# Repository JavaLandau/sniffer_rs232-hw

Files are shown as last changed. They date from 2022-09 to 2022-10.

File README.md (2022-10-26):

# Hardware project for Sniffer RS-232
The repository contains Altium Designer project for Sniffer RS-232.  

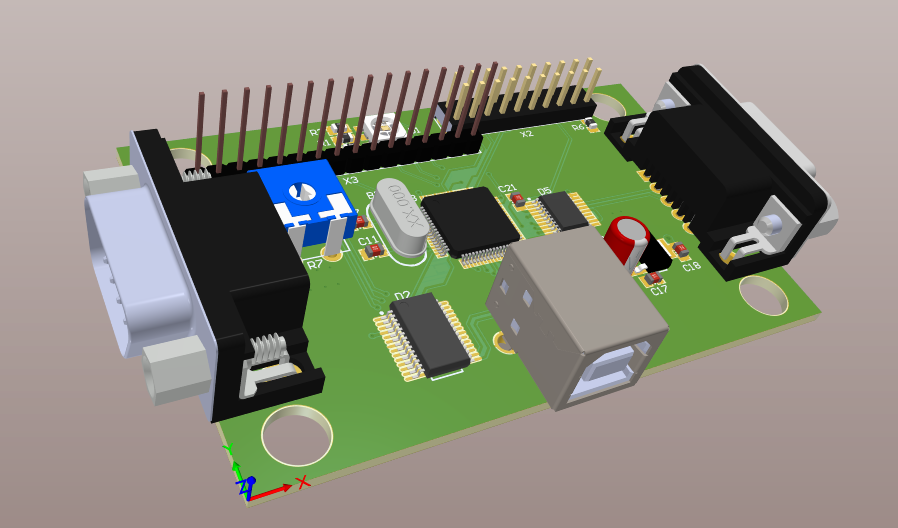
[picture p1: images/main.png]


Sniffer RS-232 is RS-232 autodetector & monitor which can recognize UART parameters on TX & RX RS-232 lines  
(baudrate, word length, parity bit) and output monitored data via USB using COM terminal (have been tested on [PuTTY](https://www.putty.org/) and [TeraTerm](https://ttssh2.osdn.jp/index.html.en)).  

The device is designed so to be connected to RS-232 line, passing traffic through itself working as repeater for TX & RX channels.  
It allows Sniffer RS-232 to be transparent for working of target devices which use RS-232. Scheme of normal work of Sniffer RS-232 is on picture below.

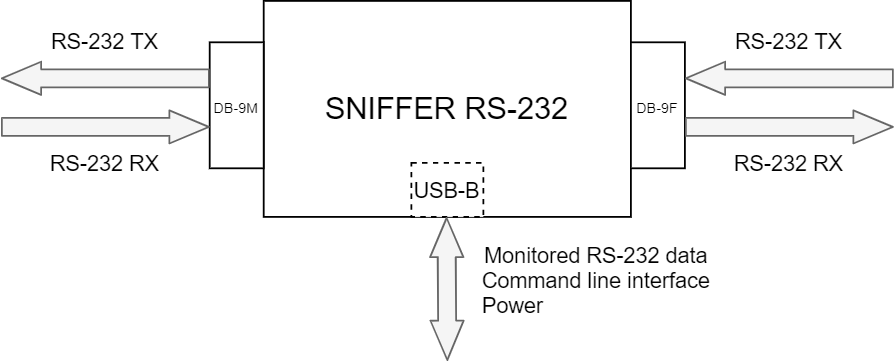
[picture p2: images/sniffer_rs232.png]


It is not compalsory to use Sniffer RS-232 by scheme above, it can be connected to one or both RS-232 lines in parallel for example.  

Despite of the fact that the device is designed to monitor RS-232 data, it also can be useful for LIN monitoring.  
In order to use feature of LIN detection & monitoring it requires to connect hardware LIN interface to Sniffer RS-232 as it done below, for example  



The device is designed to communicate with display [LCD1602A](https://www.openhacks.com/uploadsproductos/eone-1602a1.pdf)

The project is also available in the [PCBWay](https://www.pcbway.com/project/shareproject/Sniffer_RS_232_537dda4e.html)  
The firmware for the project is available in the repository [sniffer_rs232-fw](https://github.com/JavaLandau/sniffer_rs232-fw)

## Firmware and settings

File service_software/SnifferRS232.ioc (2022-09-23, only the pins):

Mcu.UserName=STM32F446RCTx
PA0-WKUP.GPIO_Label=CLI_TX
PA0-WKUP.Signal=UART4_TX
PA1.GPIO_Label=CLI_RX
PA1.Signal=UART4_RX
PA10.Signal=S_TIM1_CH3
PA13.Signal=SYS_JTMS-SWDIO
PA14.Signal=SYS_JTCK-SWCLK
PA3.GPIO_Label=RS232_TX
PA3.Signal=USART2_RX
PA6.GPIO_Label=E
PA6.Signal=GPIO_Output
PA8.Signal=S_TIM1_CH1
PA9.Signal=S_TIM1_CH2
PB0.GPIO_Label=RS
PB0.Signal=GPIO_Output
PB4.GPIO_Label=Button
PB4.Signal=GPIO_Input
PC11.GPIO_Label=D7
PC11.Signal=GPIO_Output
PC12.GPIO_Label=D6
PC12.Signal=GPIO_Output
PC13.GPIO_Label=D2
PC13.Signal=GPIO_Output
PC14-OSC32_IN.GPIO_Label=D1
PC14-OSC32_IN.Signal=GPIO_Output
PC15-OSC32_OUT.GPIO_Label=D0
PC15-OSC32_OUT.Signal=GPIO_Output
PC4.GPIO_Label=R\\W
PC4.Signal=GPIO_Output
PC5.GPIO_Label=RS232_RX
PC5.Signal=USART3_RX
PC7.GPIO_Label=D3
PC7.Signal=GPIO_Output
PC8.GPIO_Label=D4
PC8.Signal=GPIO_Output
PC9.GPIO_Label=D5
PC9.Signal=GPIO_Output
PH0-OSC_IN.Signal=RCC_OSC_IN
PH1-OSC_OUT.Signal=RCC_OSC_OUT

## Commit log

2022-08-17 Hidden label FT232RL
    [SnifferRS232.SchDoc]
2022-09-23 Updated STM32CubeMX project in part of pin's settings Add label for JTRST usage
    [SnifferRS232.SchDoc]
2022-10-21 #1 Reroute RS-232 TX/RX to UART supported pins
    Nets GPIO TX/RX are rerouted to USART2 RX/USART3 RX pins of STM32
    [SnifferRS232.SchDoc]
2022-10-24 License changed to CERN OHL v2 Permissive Resistor & capacitors values in English notation
    [SnifferRS232.SchDoc]
2022-10-24 Renamed power nets in English notation
    [SnifferRS232.SchDoc]
2022-10-30 Changed values of resistors & capacitors in English notation
    [SnifferRS232.SchDoc]
